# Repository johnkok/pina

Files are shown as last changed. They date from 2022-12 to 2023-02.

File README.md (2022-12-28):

# PINA Project - Raspberry Pico-w energy meter

The aim of this project it to create a ultra precise energy meter based on INA228 TI's energy meter device. INA228 is a 20-bit energy meter device, with I2C host interface capable of measuring voltage/current/energy at sampling rates up to 20KHz. Device is connected with a Raspberry Pico W host acquiring the data from the I2C interface and communicating with the host through the WiFi interface using a TCP protocol. In addition, the Pico w module will be able to store IO level on DUT (Device Under Test) and transmit the data to the host application.  
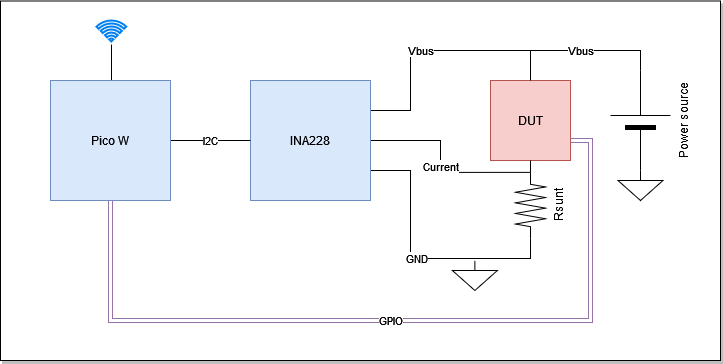
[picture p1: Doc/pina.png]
PINA
  
On the host side, a basic driver implemented for libsigrok for communicating with the Pico W firmware and propagating the data to sigrok suite. Patched version of sigrok library located at the following location: https://github.com/johnkok/libsigrok

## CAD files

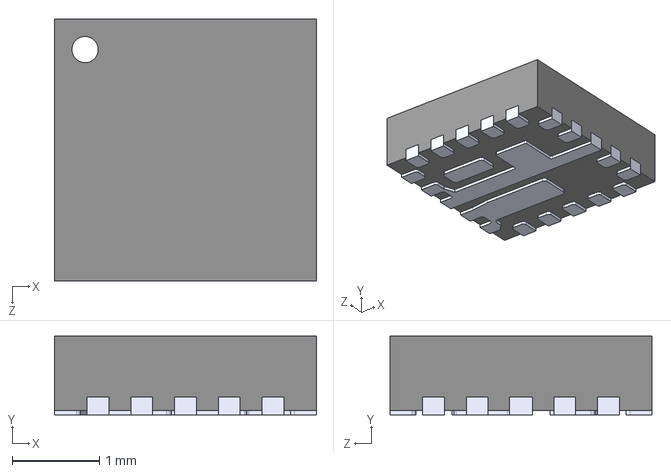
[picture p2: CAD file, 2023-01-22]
HW/pina/MIC24045-EIYFL-TR.step
3.00 x 0.9 x 3.00 mm

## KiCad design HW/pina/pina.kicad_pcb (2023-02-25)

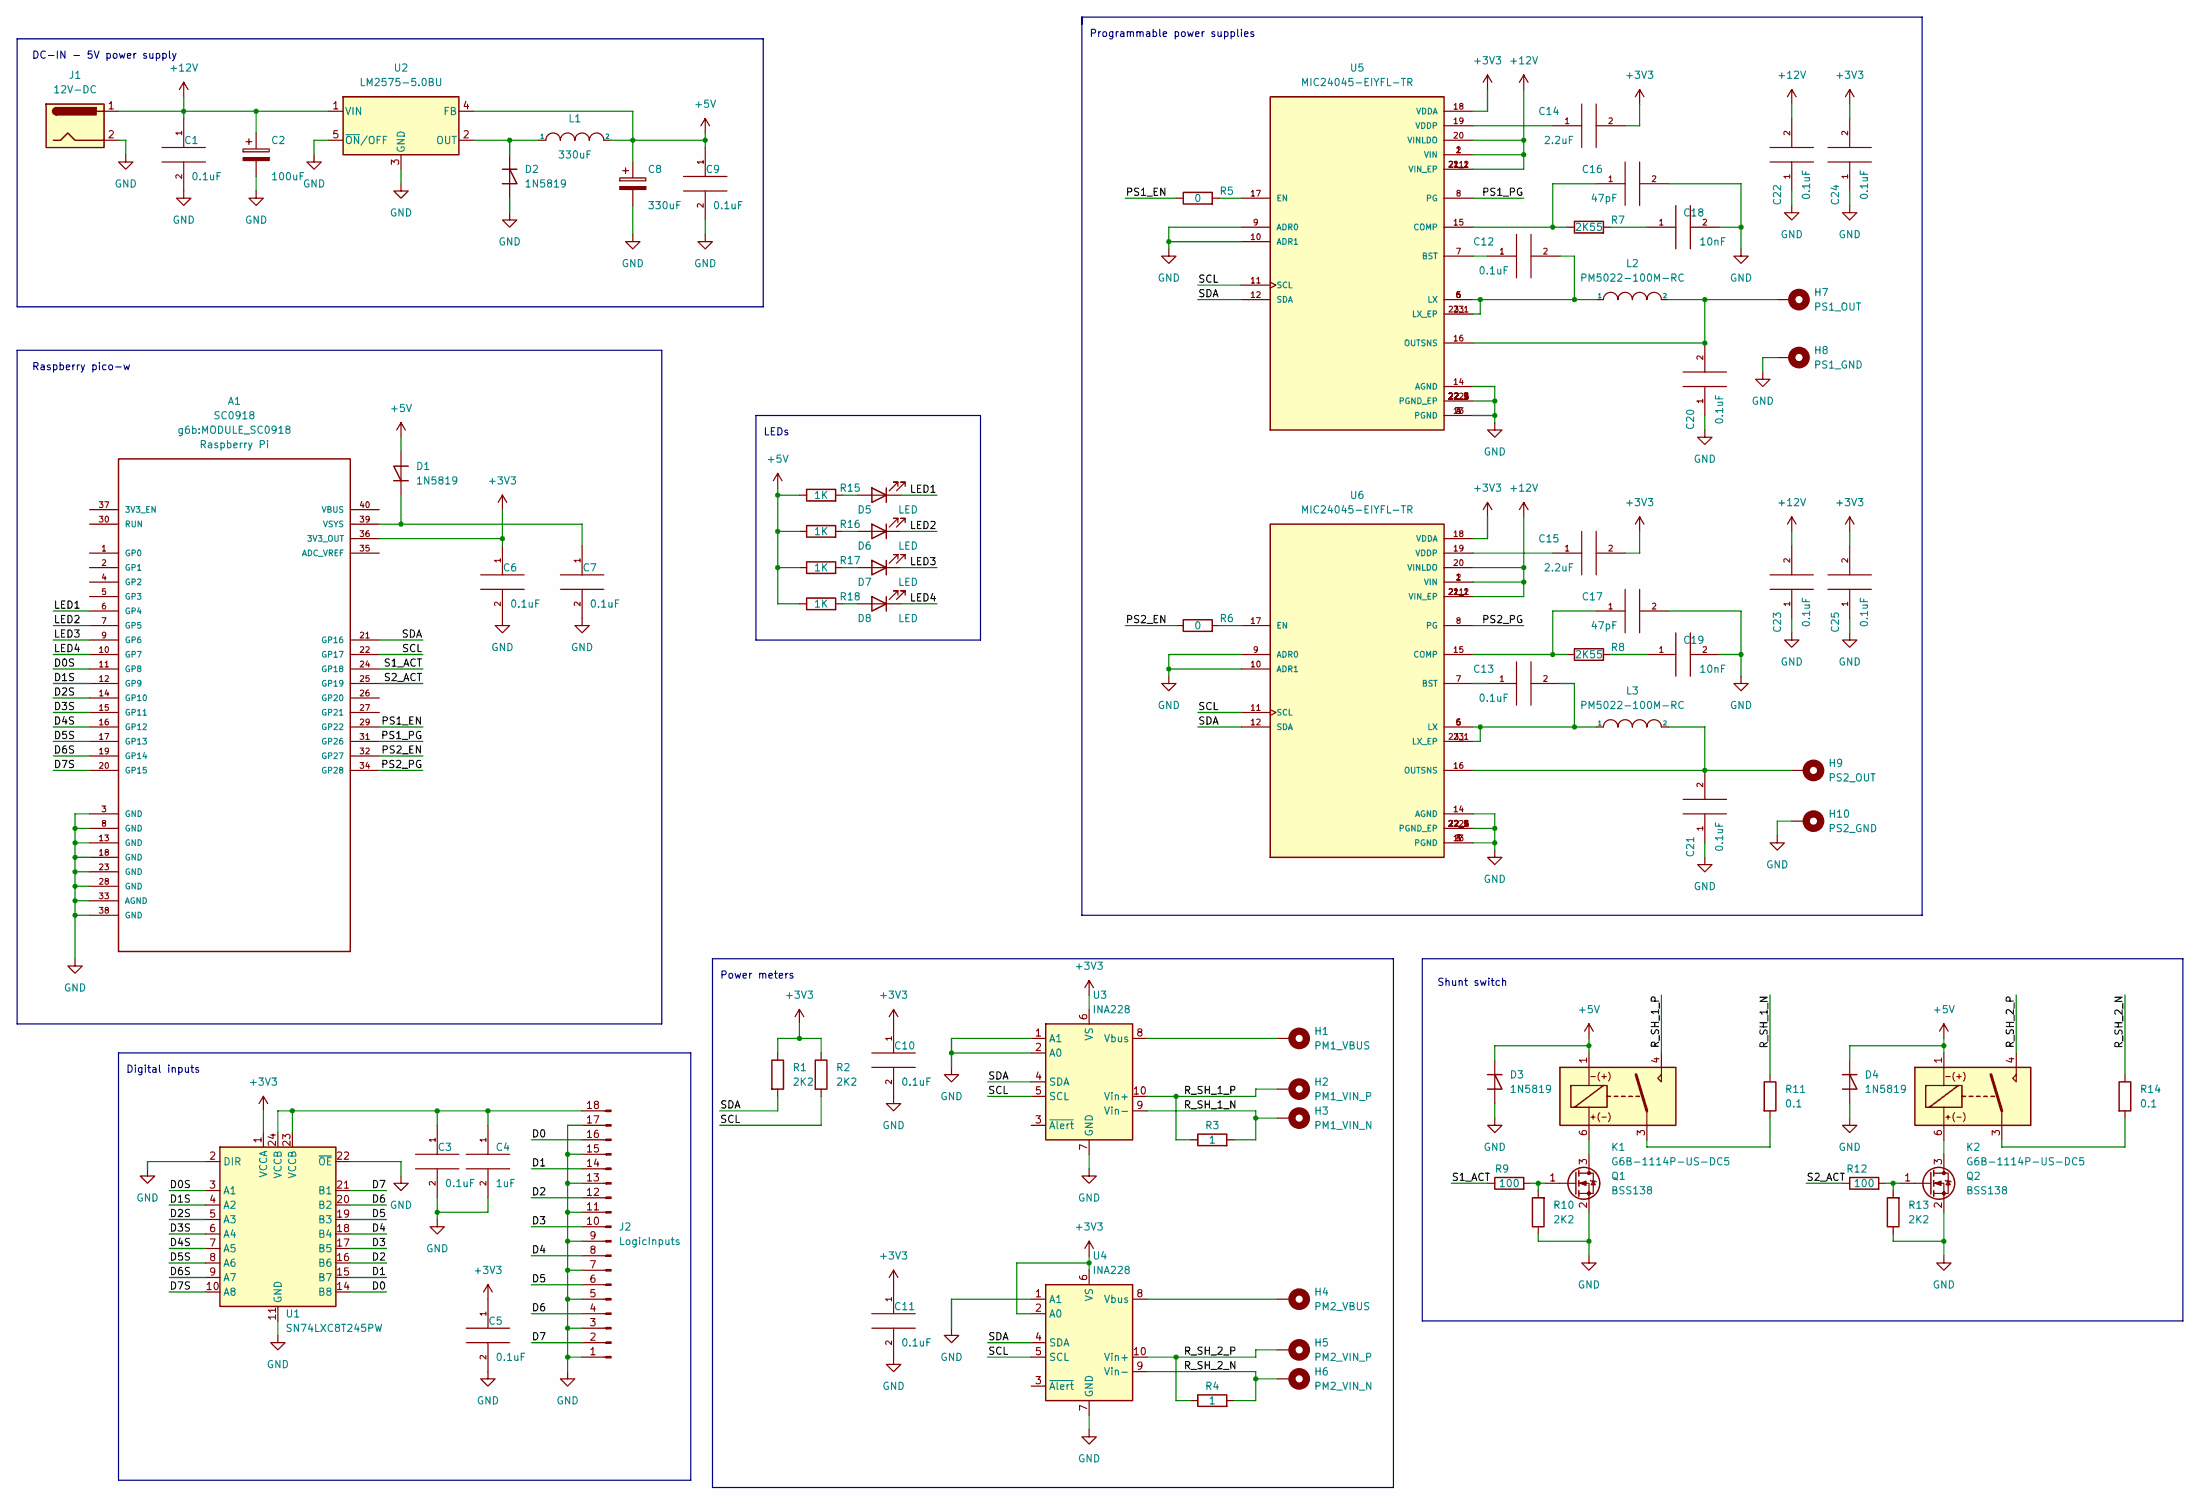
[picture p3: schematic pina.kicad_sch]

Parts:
A1: SC0918; MODULE_SC0918; PARTREV 1.6
C1, C3, C5, C6, C7, C9, C10, C11, C12, C13, C20, C21, C22, C23, C24, C25: 0.1uF; C_0603_1608Metric_Pad1.08x0.95mm_HandSolder
C2: 100uF; CP_Elec_8x11.9
C4: 1uF; C_0603_1608Metric_Pad1.08x0.95mm_HandSolder
C8: 330uF; CP_Elec_8x11.9
C14, C15: 2.2uF; C_0805_2012Metric_Pad1.18x1.45mm_HandSolder
C16, C17: 47pF; C_0603_1608Metric_Pad1.08x0.95mm_HandSolder
C18, C19: 10nF; C_0603_1608Metric_Pad1.08x0.95mm_HandSolder
D1, D2, D3, D4: 1N5819; D_SOD-123F
D5, D6, D7, D8: LED; LED_0603_1608Metric_Pad1.05x0.95mm_HandSolder
H1: PM1_VBUS; Banana_Jack_1Pin
H2: PM1_VIN_P; Banana_Jack_1Pin
H3: PM1_VIN_N; Banana_Jack_1Pin
H4: PM2_VBUS; Banana_Jack_1Pin
H5: PM2_VIN_P; Banana_Jack_1Pin
H6: PM2_VIN_N; Banana_Jack_1Pin
H7: PS1_OUT; Banana_Jack_1Pin
H8: PS1_GND; Banana_Jack_1Pin
H9: PS2_OUT; Banana_Jack_1Pin
H10: PS2_GND; Banana_Jack_1Pin
J1: 12V-DC; BarrelJack_GCT_DCJ200-10-A_Horizontal
J2: LogicInputs; PinHeader_2x09_P2.54mm_Vertical
K1, K2: G6B-1114P-US-DC5; RELAY_G6B_1114
L1: 330uF; L_12x12mm_H6mm
L2, L3: PM5022-100M-RC; L_Bourns_SDR1806
Q1, Q2: BSS138; SOT-23
R1, R2, R10, R13: 2K2; R_0603_1608Metric_Pad0.98x0.95mm_HandSolder
R3, R4: 1; R_1206_3216Metric_Pad1.30x1.75mm_HandSolder
R5, R6: 0; R_0603_1608Metric_Pad0.98x0.95mm_HandSolder
R7, R8: 2K55; R_0603_1608Metric_Pad0.98x0.95mm_HandSolder
R9, R12: 100; R_0603_1608Metric_Pad0.98x0.95mm_HandSolder
R11, R14: 0.1; R_1206_3216Metric_Pad1.30x1.75mm_HandSolder
R15, R16, R17, R18: 1K; R_0603_1608Metric_Pad0.98x0.95mm_HandSolder
U1: SN74LXC8T245PW; TSSOP-24_4.4x7.8mm_P0.65mm
U2: LM2575-5.0BU; TO-263-5_TabPin3
U3, U4: INA228; VSSOP-10_3x3mm_P0.5mm
U5, U6: MIC24045-EIYFL-TR; CONV_MIC24045-EIYFL-TR; PARTREV B

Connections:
+3V3: A1.36 (3V3_OUT), C5.1, C6.1, C10.1, C11.1, C14.2, C15.2, C24.2, C25.2, R1.1, R2.1, U1.1 (VCCA), U3.6 (VS), U4.2 (A0), U4.6 (VS), U5.18 (VDDA), U6.18 (VDDA)
+5V: C8.1, C9.1, D1.2 (A), D3.1 (K), D4.1 (K), K1.1, K2.1, L1.2, R15.1, R16.1, R17.1, R18.1, U2.4 (FB)
+12V: C1.1, C2.1, C22.2, C23.2, J1.1, U2.1 (VIN), U5.1 (VIN), U5.2 (VIN), U5.20 (VINLDO), U5.21 (VIN_EP), U5.21_1 (VIN_EP), U5.21_2 (VIN_EP), U6.1 (VIN), U6.2 (VIN), U6.20 (VINLDO), U6.21 (VIN_EP), U6.21_1 (VIN_EP), U6.21_2 (VIN_EP)
/D0: J2.16, U1.14 (B8)
/D0S: A1.11 (GP8), U1.3 (A1)
/D1: J2.14, U1.15 (B7)
/D1S: A1.12 (GP9), U1.4 (A2)
/D2: J2.12, U1.16 (B6)
/D2S: A1.14 (GP10), U1.5 (A3)
/D3: J2.10, U1.17 (B5)
/D3S: A1.15 (GP11), U1.6 (A4)
/D4: J2.8, U1.18 (B4)
/D4S: A1.16 (GP12), U1.7 (A5)
/D5: J2.6, U1.19 (B3)
/D5S: A1.17 (GP13), U1.8 (A6)
/D6: J2.4, U1.20 (B2)
/D6S: A1.19 (GP14), U1.9 (A7)
/D7: J2.2, U1.21 (B1)
/D7S: A1.20 (GP15), U1.10 (A8)
/LED1: A1.6 (GP4), D5.1 (K)
/LED2: A1.7 (GP5), D6.1 (K)
/LED3: A1.9 (GP6), D7.1 (K)
/LED4: A1.10 (GP7), D8.1 (K)
/PS1_EN: A1.29 (GP22), R5.1
/PS1_PG: A1.31 (GP26), U5.8 (PG)
/PS2_EN: A1.32 (GP27), R6.1
/PS2_PG: A1.34 (GP28), U6.8 (PG)
/R_SH_1_N: H3.1, R3.2, R11.1, U3.9 (Vin-)
/R_SH_1_P: H2.1, K1.4, R3.1, U3.10 (Vin+)
/R_SH_2_N: H6.1, R4.2, R14.1, U4.9 (Vin-)
/R_SH_2_P: H5.1, K2.4, R4.1, U4.10 (Vin+)
/S1_ACT: A1.24 (GP18), R9.1
/S2_ACT: A1.25 (GP19), R12.1
/SCL: A1.22 (GP17), R2.2, U3.5 (SCL), U4.5 (SCL), U5.11 (SCL), U6.11 (SCL)
/SDA: A1.21 (GP16), R1.2, U3.4 (SDA), U4.4 (SDA), U5.12 (SDA), U6.12 (SDA)
GND: A1.3 (GND), A1.8 (GND), A1.13 (GND), A1.18 (GND), A1.23 (GND), A1.28 (GND), A1.33 (AGND), A1.38 (GND), C1.2, C2.2, C3.2, C4.2, C5.2, C6.2, C7.2, C8.2, C9.2, C10.2, C11.2, C16.2, C17.2, C18.2, C19.2, C20.1, C21.1, C22.1, C23.1, C24.1, C25.1, D2.2 (A), D3.2 (A), D4.2 (A), H8.1, H10.1, J1.2, J2.1, J2.3, J2.5, J2.7, J2.9, J2.11, J2.13, J2.15, J2.17, Q1.2 (S), Q2.2 (S), R10.1, R13.1, U1.2 (DIR), U1.11 (GND), U1.12 (GND), U1.13 (GND), U1.22 (~OE), U2.3 (GND), U2.5 (~ON/OFF), U3.1 (A1), U3.2 (A0), U3.7 (GND), U4.1 (A1), U4.7 (GND), U5.3 (PGND), U5.4 (PGND), U5.9 (ADR0), U5.10 (ADR1), U5.13 (PGND), U5.14 (AGND), U5.22 (PGND_EP), U5.22_1 (PGND_EP), U5.22_2 (PGND_EP), U5.22_3 (PGND_EP), U5.22_4 (PGND_EP), U5.22_5 (PGND_EP), U6.3 (PGND), U6.4 (PGND), U6.9 (ADR0), U6.10 (ADR1), U6.13 (PGND), U6.14 (AGND), U6.22 (PGND_EP), U6.22_1 (PGND_EP), U6.22_2 (PGND_EP), U6.22_3 (PGND_EP), U6.22_4 (PGND_EP), U6.22_5 (PGND_EP)
unnamed: A1.39 (VSYS), C7.1, D1.1 (K)
unnamed: C3.1, C4.1, J2.18, U1.23 (VCCB), U1.24 (VCCB)
unnamed: C12.1, U5.7 (BST)
unnamed: C12.2, L2.1, U5.5 (LX), U5.6 (LX), U5.23 (LX_EP), U5.23_1 (LX_EP)
unnamed: C13.1, U6.7 (BST)
unnamed: C13.2, L3.1, U6.5 (LX), U6.6 (LX), U6.23 (LX_EP), U6.23_1 (LX_EP)
unnamed: C14.1, U5.19 (VDDP)
unnamed: C15.1, U6.19 (VDDP)
unnamed: C16.1, R7.1, U5.15 (COMP)
unnamed: C17.1, R8.1, U6.15 (COMP)
unnamed: C18.1, R7.2
unnamed: C19.1, R8.2
unnamed: C20.2, H7.1, L2.2, U5.16 (OUTSNS)
unnamed: C21.2, H9.1, L3.2, U6.16 (OUTSNS)
unnamed: D2.1 (K), L1.1, U2.2 (OUT)
unnamed: D5.2 (A), R15.2
unnamed: D6.2 (A), R16.2
unnamed: D7.2 (A), R17.2
unnamed: D8.2 (A), R18.2
unnamed: H1.1, U3.8 (Vbus)
unnamed: H4.1, U4.8 (Vbus)
unnamed: K1.3, R11.2
unnamed: K1.6, Q1.3 (D)
unnamed: K2.3, R14.2
unnamed: K2.6, Q2.3 (D)
unnamed: Q1.1 (G), R9.2, R10.2
unnamed: Q2.1 (G), R12.2, R13.2
unnamed: R5.2, U5.17 (EN)
unnamed: R6.2, U6.17 (EN)

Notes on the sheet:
DC-IN - 5V power supply
LEDs
Programmable power supplies
Raspberry pico-w
Power meters
Shunt switch
Digital inputs

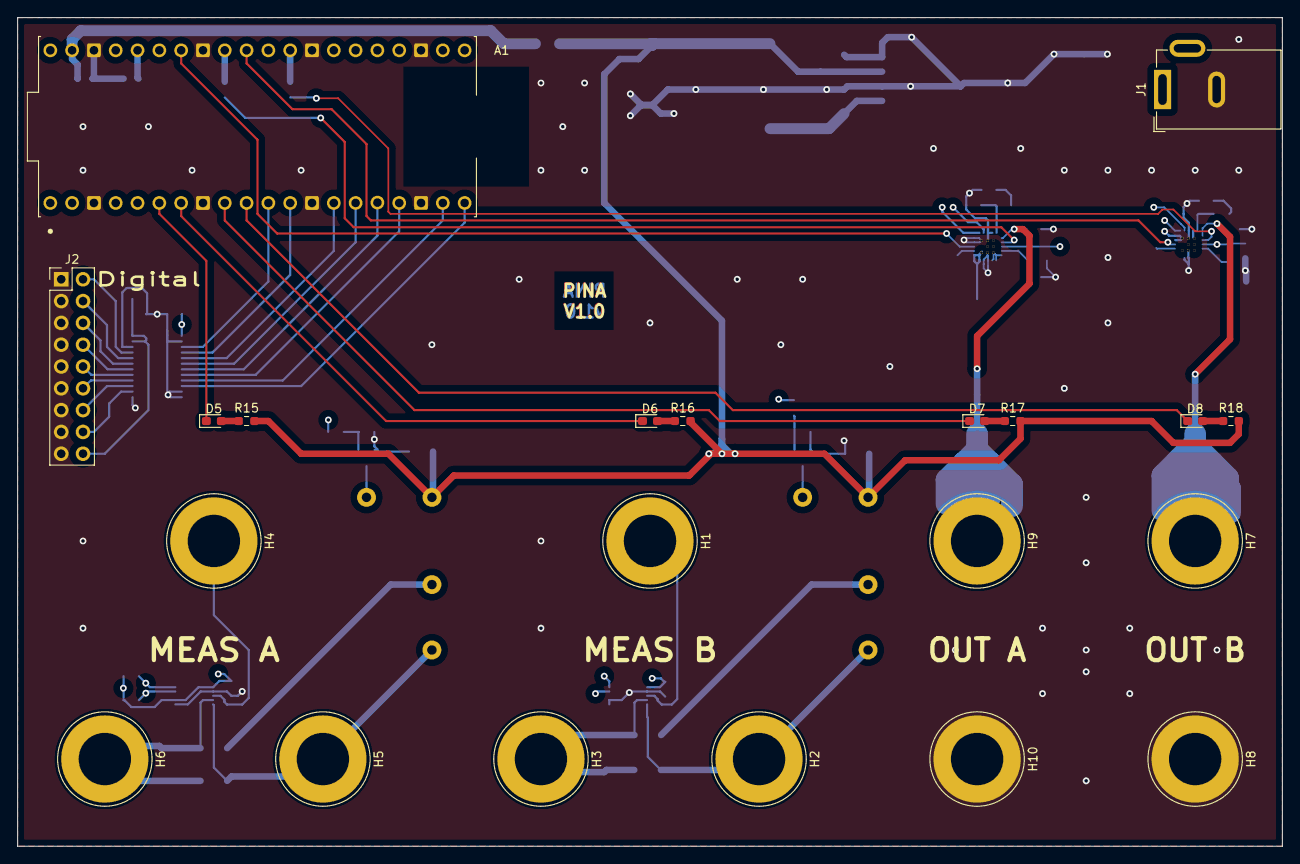
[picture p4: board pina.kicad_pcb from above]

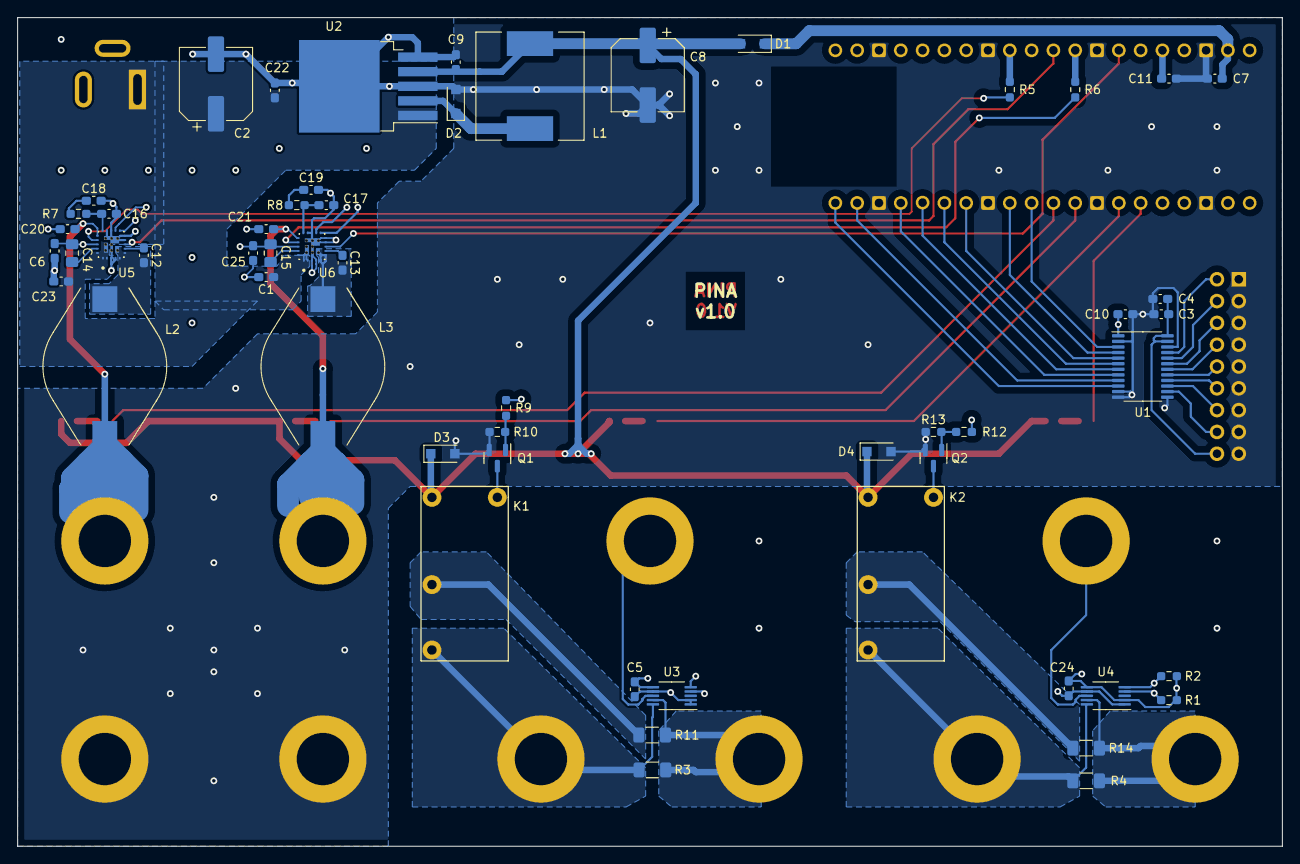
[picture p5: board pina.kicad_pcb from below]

Board: 4 copper layers, 147.3 x 96.5 mm, 77 parts (56 on the bottom side), 65 nets.

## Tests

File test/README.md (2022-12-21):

Rasberry Pico-w Energey meter test folder

test_server.c: TCP protocol simulation server.

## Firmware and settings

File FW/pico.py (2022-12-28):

import network
import time
import socket
import select
import _thread
import struct
from time import sleep
from machine import Pin
from machine import Timer

# WiFi Access Point data
SSID = ""
PASSWORD = ""

# INA I2C Registers
INA_ADDRESS    = 0x40
INA_CONFIG     = 0x00
INA_ADC_CONFIG = 0x01
INA_SHUNT_CAL  = 0x02
INA_VBUS       = 0x05
INA_CURRENT    = 0x07
INA_CHARGE     = 0x0A

# Init hardware
led = machine.Pin("LED", machine.Pin.OUT)
tim = machine.Timer()

led.value(0)

# Global varibles
tx_enable = False
connected = False
new_data = False

rate = 10
unit = 1
malloc = 16

ch_id: int
gpio: int
vbus: float
isense: float

ch_id = 1
isense = 0.0
vbus = 0.0

# WiFi connection handling
def connect(): #WIFI connection
    wlan = network.WLAN(network.STA_IF)
    wlan.active(True)
    wlan.connect(SSID, PASSWORD)
    while wlan.isconnected() == False:
        print('Waiting for connection...')
        sleep(1)
    ip = wlan.ifconfig()[0]
    print(f'Connected on {ip}')
    return ip

# TCP Server handler
def tcpserver():
    global tx_enable
    global connected
    global connection

    try:
        led.value(1)

        # Receive the data in small chunks and process it
        while True:
            data = connection.readline()
            if data:
                string = data.decode('ascii')
                print('Rx data: ', string)
                if string.startswith('version'):
                    connection.send('PINA')
                elif string.startswith('get'):
                    tx_enable = True
                elif string.startswith('close'):
                    tx_enable = False
                elif string.startswith('samplerate'):
                    connection.send(chr(rate))
                elif string.startswith('sampleunit'):
                    connection.send(chr(unit))
                elif string.startswith('memalloc'):
                    connection.send(chr(malloc))
                elif string.startswith('exit'):
                    tx_enable = False
                    connection.close()
                    break # Disconnect
                else:
                    print('Unknown data {}'.format(data))
            else:
                print ('no data')
                break
    finally:
        # Clean up the connection
        connection.close()
        connected = False
        led.value(0)
        print("Connection closed!")

# INA228 Driver
def ina228():
    global vbus
    global isense
    global new_data
    global i2c

    if new_data == False:
        data = i2c.readfrom_mem(0x40, INA_CURRENT, 3)
        value = ((data[0] & 0x7F) << 12) + (data[1] << 4) + data[2] >> 4
        if (data[0] & 0x80):
            value = -value
        isense = value * 1.5625 / 1000.0 / 1000.0
        #print('Current: {} mA'.format(isense))

        data = i2c.readfrom_mem(0x40, INA_VBUS, 3)
        value = (data[0] << 12) + (data[1] << 4) + (data[2] >> 4)
        vbus = (value * 195.3125) / 1000000.0
        #print('Voltage: {} V'.format(vbus))

        data = i2c.readfrom_mem(0x40, INA_CHARGE, 5)
        value = ((data[0] & 0x80) << 24) + (data[1] << 20) + (data[2] << 16) + (data[3] << 8) + (data[4])
        #print('Charge: {} V'.format((value * 195.3125) / 1000000.0))

        new_data = True

# Timer callback
def timerCallback(t):
    global vbus
    global isense
    global new_data
    global ch_id
    global connected
    global connection
    global gpio
    global IO0
    global IO1
    global IO2
    global IO3
    global IO4
    global IO5
    global IO6
    global IO7

    if connected and tx_enable:
        ina228()
        if new_data:
            gpio = IO0.value() + IO1.value()*2 + IO2.value()*4 + IO3.value()*8 + IO4.value()*16 + IO5.value()*32 + IO6.value()*64 + IO7.value()*128
            packet = bytearray(struct.pack("iffi", ch_id, isense, vbus, gpio))
            connection.write(packet)
            print(gpio)
            print(IO0.value())
            new_data = False

############
#   main   #
############
try:
    # Try to connect to WiFi AP
    ip = connect()  # Prepare WiFi connection
    # Should be connected to WiFi now

    # Connect to INA228
    i2c = machine.I2C(0, scl=machine.Pin(17), sda=machine.Pin(16))
    devices = i2c.scan()
    if devices:
        for d in devices:
            if d == INA_ADDRESS:
                print("INA228 found!")

                #setup ina 228
                i2c.writeto_mem(INA_ADDRESS, INA_CONFIG, bytearray([0x00,0x00]))
                i2c.writeto_mem(INA_ADDRESS, INA_ADC_CONFIG, bytearray([0xFB, 0x6A]))
                # R = 0.2 Ohm -> 163.84 mV = 819.2mA MAX -> 1,5625uA MIN
                # SHUNT_CAL = 13107.2 x 106 x CURRENT_LSB x RSHUNT
                # CURRENT_LSB = Maximum Expected Current / 2^19
                i2c.writeto_mem(INA_ADDRESS, INA_SHUNT_CAL, bytearray([0x10, 0x00]))

            else:
                print("No INA228 found!")
                exit

    # Setup GPIOs
    IO0 = Pin(8, Pin.IN)
    IO1 = Pin(9, Pin.IN)
    IO2 = Pin(10, Pin.IN)
    IO3 = Pin(11, Pin.IN)
    IO4 = Pin(12, Pin.IN)
    IO5 = Pin(13, Pin.IN)
    IO6 = Pin(14, Pin.IN)
    IO7 = Pin(15, Pin.IN)

    # Create data acq timer
    tim.init(mode=Timer.PERIODIC, period=200, callback=timerCallback)

    # Create a TCP/IP socket and bind it
    sock = socket.socket(socket.AF_INET, socket.SOCK_STREAM) #tcp socket
    server_address = socket.getaddrinfo('0.0.0.0', 5555)[0][-1]
    print ('Server starting up on %s port %s' % server_address)
    sock.bind(server_address)

    # Listen for incoming connections
    sock.listen(5)
    while True:
        # Wait for a connection
        print ('Server waiting for a connection...')
        connection, client_address = sock.accept()
        connected = True
        print ('Server connection from', client_address)

        #_thread.start_new_thread(tcpserver, ())  # TCP Server thread
        tcpserver()


except KeyboardInterrupt:
    machine.reset()
    print("Reset done!")

print("Exit!")

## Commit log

2022-12-28 pico initial FW added
2022-12-28 fix pico FW
2023-01-22 Initial schematic added
    [MIC24045-EIYFL-TR.step, pina.kicad_pcb, pina.kicad_sch]
2023-01-29 Initial pcb added
    [pina.kicad_pcb, pina.kicad_sch]
2023-01-30 PCB finalized
    [pina.kicad_pcb, pina.kicad_sch]
2023-02-25 Update PCB
    [pina-B_Cu.gbl, pina-B_Mask.gbs, pina-B_Paste.gbp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]
